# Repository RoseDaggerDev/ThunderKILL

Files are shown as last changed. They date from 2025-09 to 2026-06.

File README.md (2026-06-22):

# ThunderKILL

ThunderKILL is based on the [Thundervolt](https://github.com/mackieks/thundervolt/tree/main) by [YveltalGriffin](https://github.com/mackieks) an open source platform for undervolting the Nintendo Wiis.
ThunderKILL takes the original concept and tries to go overkill with more features explicitly not inculded in the Thundervolt.
### New features:
- USB-C Power delivery
- Battery charge controller
- Fan and temperature controller
- RGB LED controller
- Current sensing
- 5V boost regulator
- E-Fuse on the PD power in
- Resettable fuse on the battery connection

### Existing features from Thundervolt:
- 1V buck regulator
- 1.15V buck regulator
- 1.8V buck regulator
- 3.3V buck boost regulator

All regulators are I2C controlled and high efficiency (η > 90%) and can be(/will be) controllable from a homebrew app. Along with the data from the I2C current/voltage/power sensing and temperature sensing of the board and the Wii.
The ThunderKILL has significantly more output pads than the original Thundervolt, as it is designed to integrate with other boards beyond the Wii itself, supplying easily available power, along with all the new features like PD negotiation, fan and LED outputs.

### ToDo:
- Final pass on board
- Send to printing
- Solder components
- Develop firmware
- Test in isolation
- Test on Wii
- Develop homebrew app

### NOTE: ThunderKILL is still in the prototype phase, and is untested, and the firmware for it has yet to be developed. I don’t recommend manufacturing ThunderKILL PCBs until development and testing are complete. This project is currently only for reference.

(This github page is still WIP, and will change as the project continues)

## Screenshots

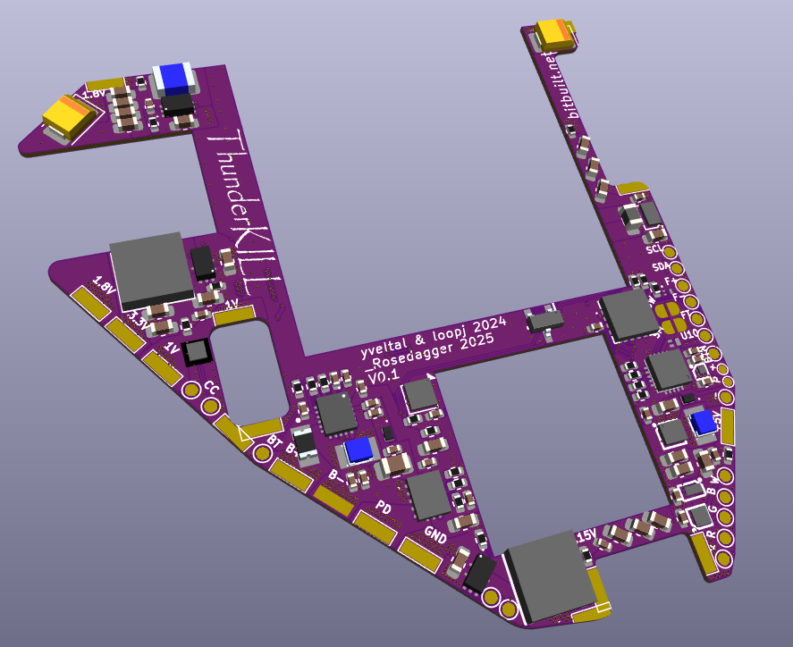
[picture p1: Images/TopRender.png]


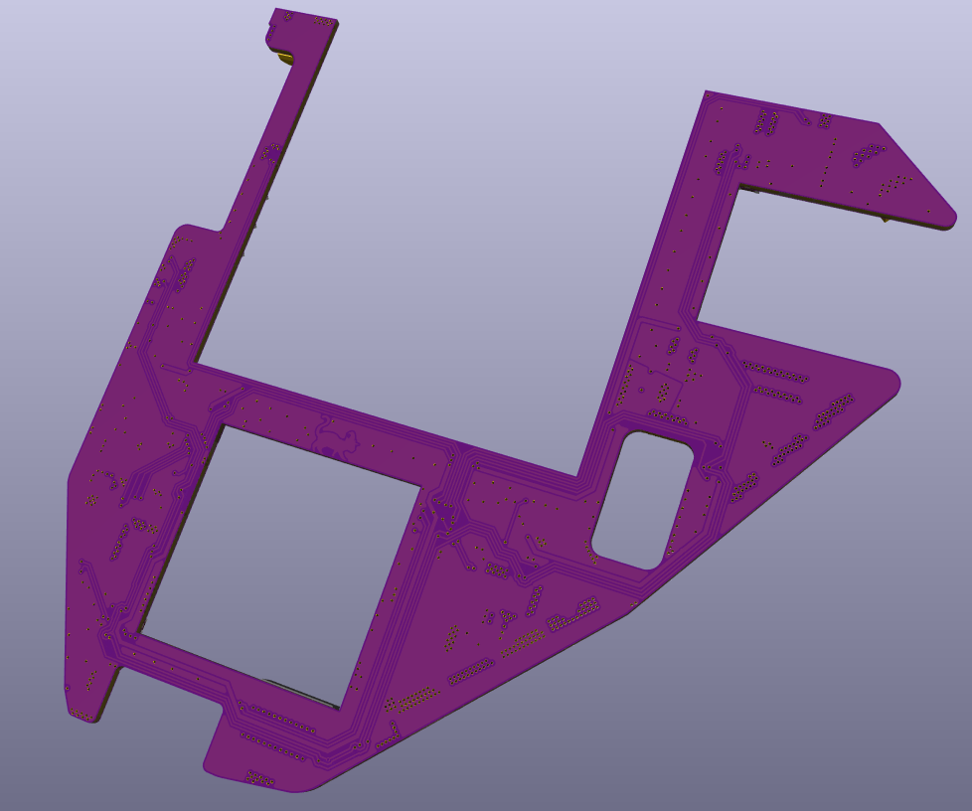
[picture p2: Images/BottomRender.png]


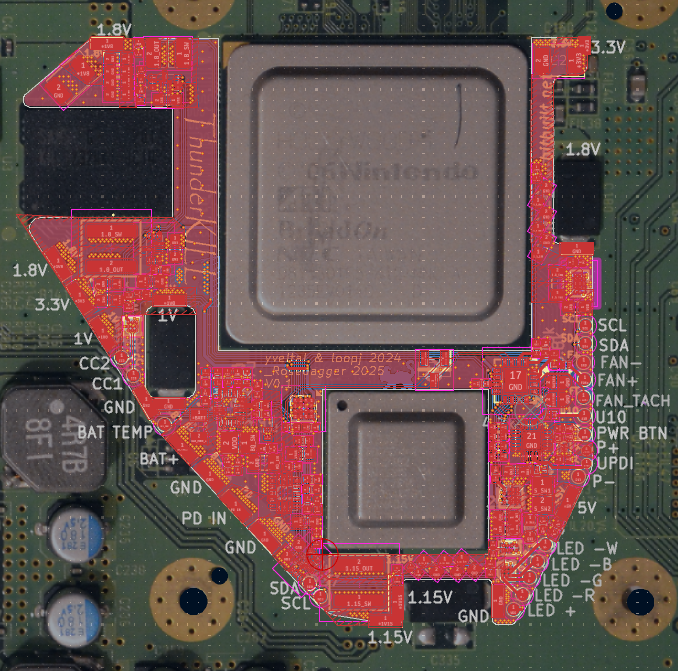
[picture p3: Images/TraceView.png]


## Credits

ThunderKILL hardware designed by [RoseDaggerDev](https://github.com/RoseDaggerDev)

Original Thundervolt credits:

Thundervolt hardware designed by [YveltalGriffin](https://github.com/mackieks)

Thundervolt firmware by [loopj ](https://github.com/loopj)

Thundervolt homebrew by:
- [YveltalGriffin](https://github.com/mackieks) (UI, app)
-  [loopj ](https://github.com/loopj) (I2C, app)
-  [Alex/supertazon](https://github.com/supertazon) (graphics)
-  [ShockSlayer ](https://github.com/ShockSlayer) (music)

## License

ThunderKILL hardware is licensed under Solderpad Hardware License v2.1.

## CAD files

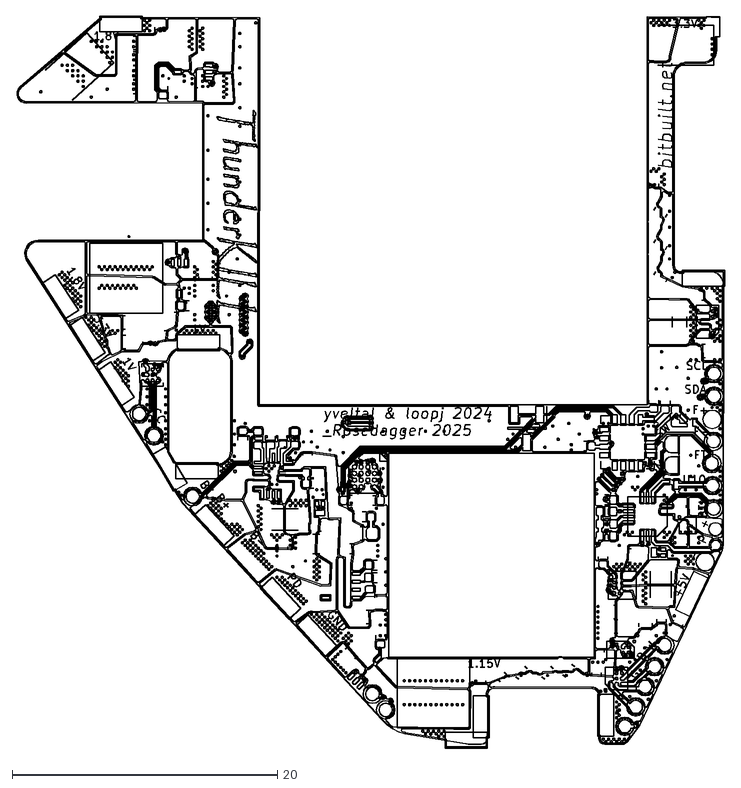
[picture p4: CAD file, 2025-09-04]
Hardware/KiCad/ThunderKillV2/Export/ThunderKillV2-Edge_Cuts.dxf
53.4 x 55.2

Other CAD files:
Hardware/KiCad/ThunderKillV2/Export/thundervolt.stl
Hardware/KiCad/ThunderKillV1/thundervolt.step
Hardware/KiCad/ThunderKillV1/thundervolt.stl

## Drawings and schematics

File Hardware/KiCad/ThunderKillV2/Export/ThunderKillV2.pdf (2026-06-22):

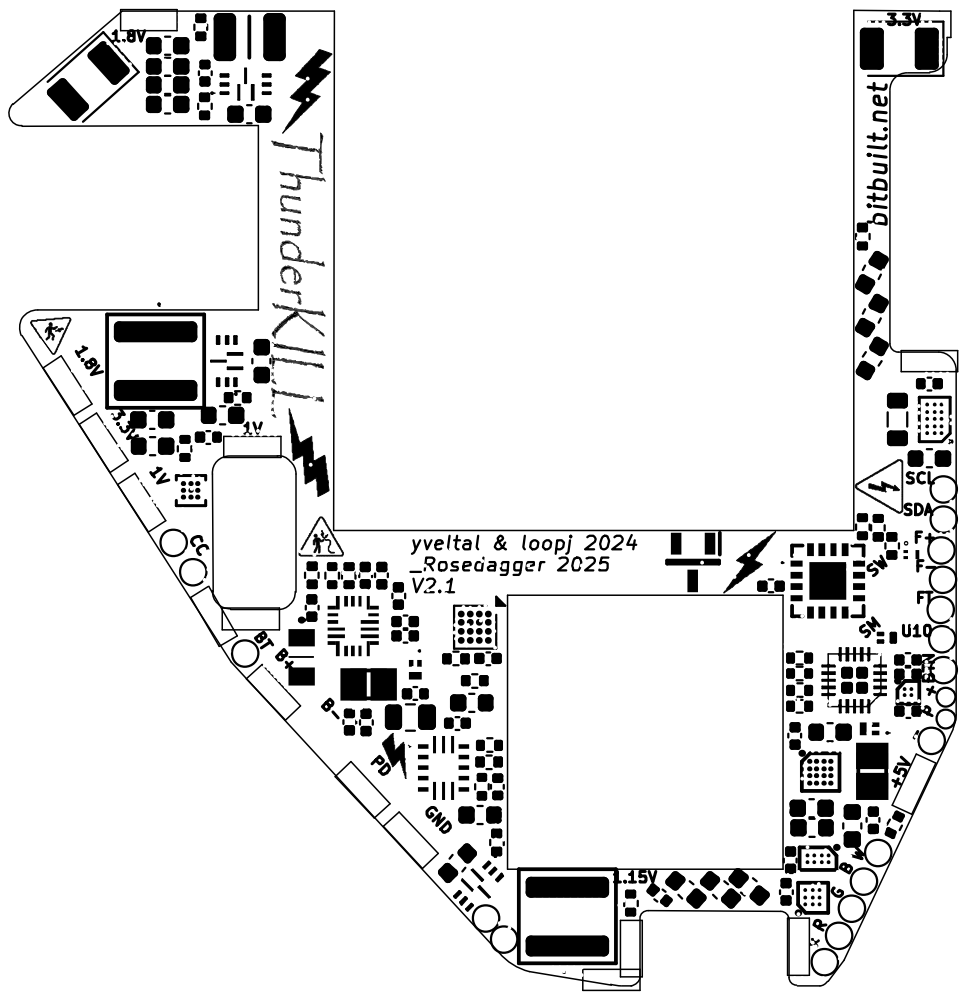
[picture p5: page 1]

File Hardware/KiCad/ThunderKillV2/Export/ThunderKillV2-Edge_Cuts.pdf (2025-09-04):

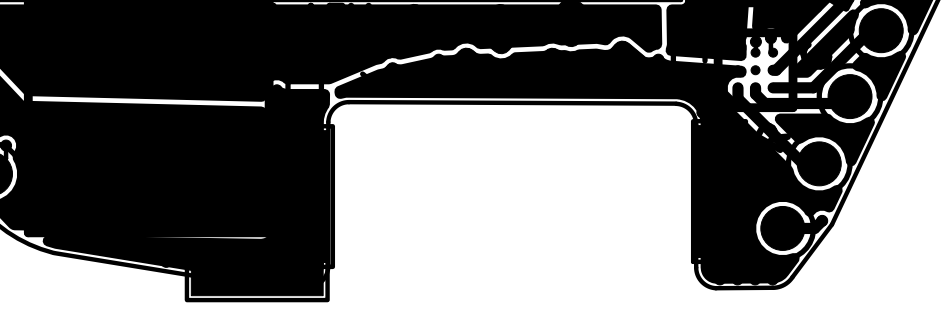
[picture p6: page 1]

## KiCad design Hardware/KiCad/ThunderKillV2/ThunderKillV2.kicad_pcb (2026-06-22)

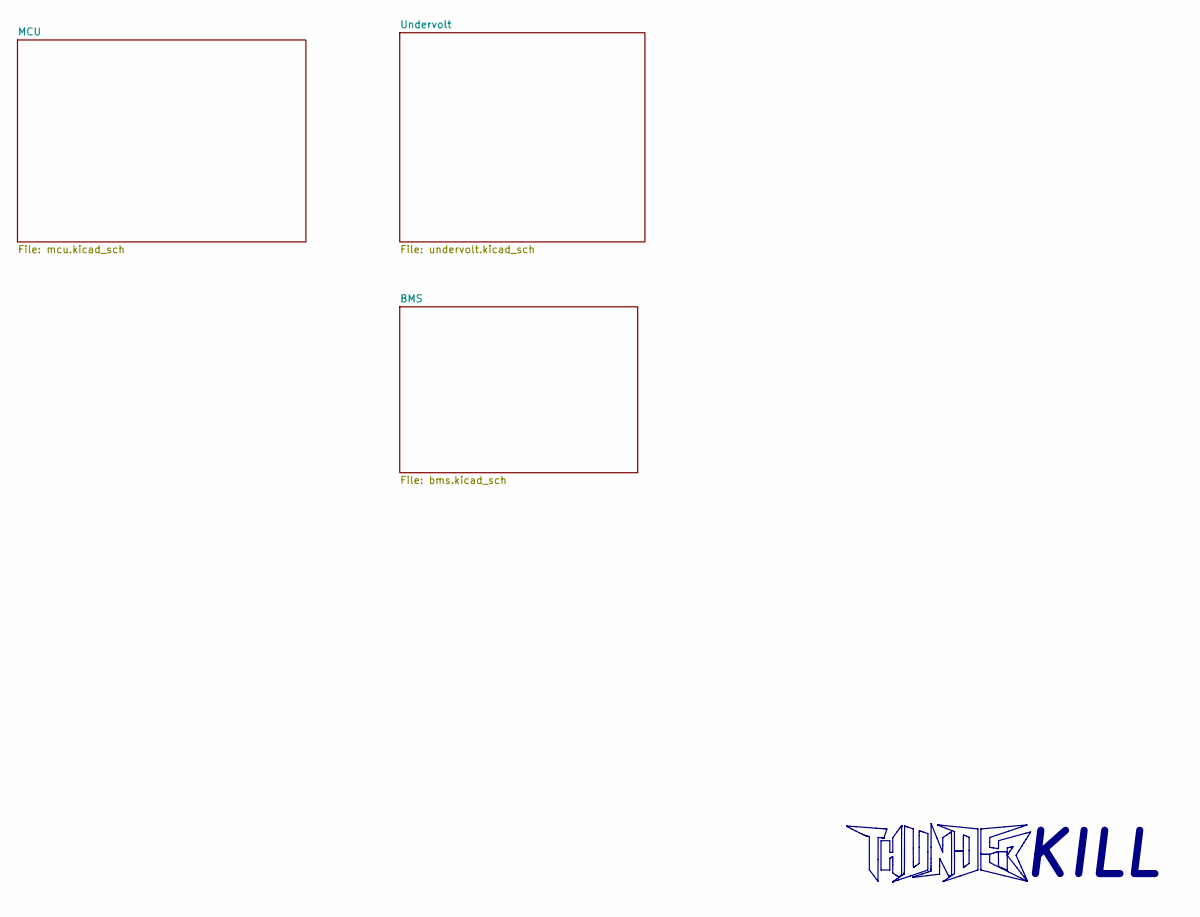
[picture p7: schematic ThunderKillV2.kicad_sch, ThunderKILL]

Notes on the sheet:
KILL

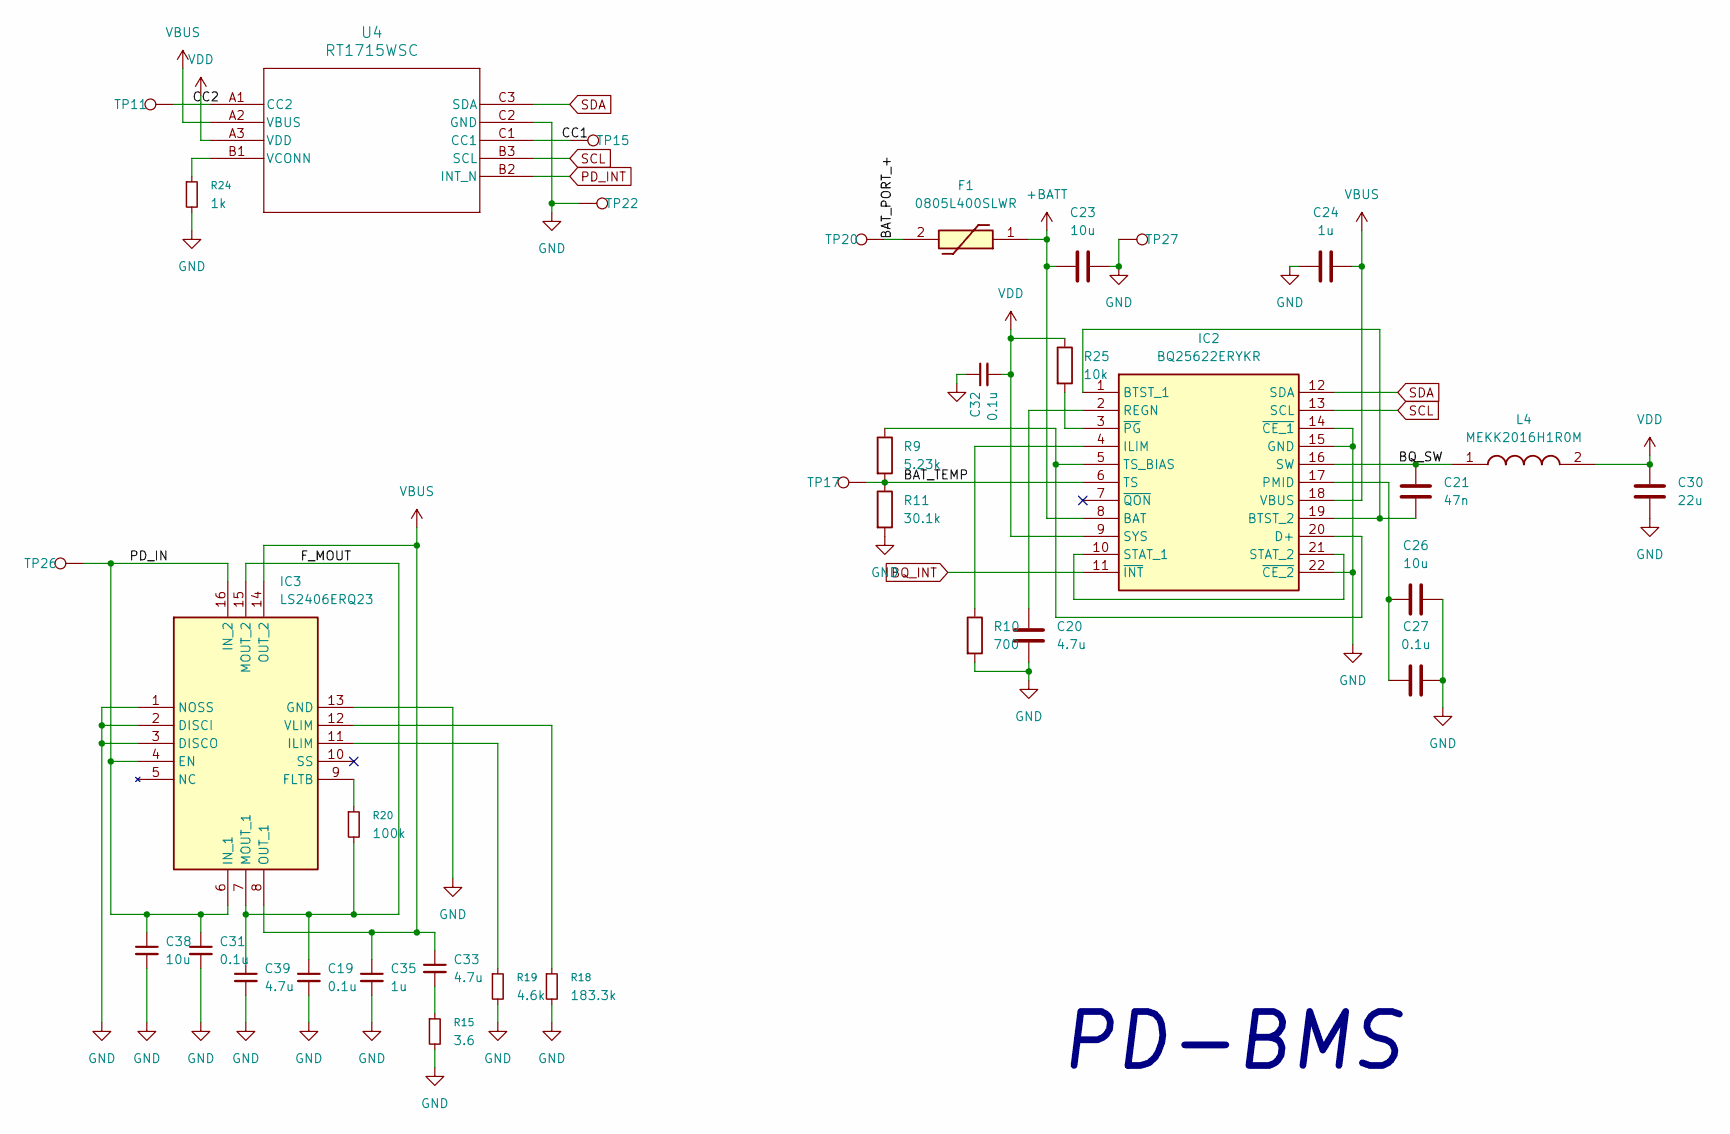
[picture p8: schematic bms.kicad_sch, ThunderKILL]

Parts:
C19, C27, C31, C32: 0.1u; C_0402_1005Metric; Manufacturer_Part_Number GCM155R71H104KE02J; Digi-Key Part # 490-14514-1-ND
C20, C33, C39: 4.7u; C_0402_1005Metric; Manufacturer_Part_Number GRM155C61E475ME15J; Digi-Key Part # 490-GRM155C61E475ME15JCT-ND
C21: 47n; C_0402_1005Metric; Manufacturer_Part_Number GRM155R71H473KE14D; Digi-Key Part # 490-10702-1-ND
C23, C26, C38: 10u; C_0603_1608Metric; Manufacturer_Part_Number GRM188R61E106KA73D; Digi-Key Part # 490-18214-1-ND
C24, C35: 1u; C_0402_1005Metric; Manufacturer_Part_Number GRM155R61E105KA12D; Digi-Key Part # 490-10017-1-ND
C30: 22u; C_0603_1608Metric; Manufacturer_Part_Number GRM188C61E226ME01W; Digi-Key Part # 490-GRM188C61E226ME01WCT-ND
F1: 0805L400SLWR; 0805L075SLYR; Mouser Part Number 576-0805L400SLWR
IC2: BQ25622ERYKR; Mouser Part Number 595-BQ25622ERYKR
IC3: LS2406ERQ23; Mouser Part Number 576-LS2406ERQ23
L4: MEKK2016H1R0M; INDPM2016X100N; Mouser Part Number 963-MEKK2016H1R0M
R9: 5.23k; R_0402_1005Metric; Manufacturer_Part_Number RMCF0402FT5K23; Digi-Key Part # RMCF0402FT5K23CT-ND
R10: 700; R_0402_1005Metric; Manufacturer_Part_Number RMCF0402FT698R; Digi-Key Part # RMCF0402FT698RCT-ND
R11: 30.1k; R_0402_1005Metric; Manufacturer_Part_Number RMCF0402FT30K1; Digi-Key Part # RMCF0402FT30K1CT-ND
R15: 3.6; R_0402_1005Metric; Manufacturer_Part_Number RMCF0402FT3R60; Digi-Key Part # RMCF0402FT3R60CT-ND
R18: 183.3k; R_0402_1005Metric; Manufacturer_Part_Number RMCF0402FT182K; Digi-Key Part # RMCF0402FT182KCT-ND
R19: 4.6k; R_0402_1005Metric; Manufacturer_Part_Number RMCF0402FT4K64; Digi-Key Part # RMCF0402FT4K64CT-ND
R20: 100k; R_0402_1005Metric; Manufacturer_Part_Number CRCW0402100KFKED; Digi-Key Part # 541-100KLCT-ND
R24: 1k; R_0402_1005Metric; Manufacturer_Part_Number CRCW04021K00FKED; Digi-Key Part # 541-1.00KLCT-ND
R25: 10k; R_0402_1005Metric; Manufacturer_Part_Number CRCW040210K0FKED; Digi-Key Part # 541-10.0KLCT-ND
TP11: CC2; TestPoint_Pad_D1.0mm
TP15: CC1; TestPoint_Pad_D1.0mm
TP17: BAT_TMP; TestPoint_Pad_D1.0mm
TP20: BAT+; TestPoint_Pad_3x1.0mm
TP22: GND; TestPoint_Pad_3x1.0mm
TP26: VBUS; TestPoint_Pad_3x1.0mm
TP27: BAT-; TestPoint_Pad_3x1.0mm
U4: RT1715WSC; BGA3X3_RT1715WSC_RIT; Manufacturer_Part_Number RT1715WSC; Digi-Key Part # RT1715WSCCT-ND

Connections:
+BATT: C23.1, F1.1, IC2.8 (BAT)
/BMS/BAT_PORT_+: F1.2, TP20.1
/BMS/BAT_TEMP: IC2.6 (TS), R9.2, R11.1, TP17.1
/BMS/BQ_SW: C21.1, IC2.16 (SW), L4.1
/BMS/CC1: TP15.1, U4.C1 (CC1)
/BMS/CC2: TP11.1, U4.A1 (CC2)
/BMS/F_MOUT: C19.1, C39.1, IC3.7 (MOUT_1), IC3.15 (MOUT_2), R20.2
/BMS/PD_IN: C31.1, C38.1, IC3.4 (EN), IC3.6 (IN_1), IC3.16 (IN_2), TP26.1
BQ_INT: IC2.11 (~INT); also elsewhere on the board
GND: C19.2, C20.2, C23.2, C24.1, C26.2, C27.2, C30.2, C31.2, C32.1, C35.2, C38.2, C39.2, IC2.14 (~CE_1), IC2.15 (GND), IC2.22 (~CE_2), IC3.1 (NOSS), IC3.2 (DISCI), IC3.3 (DISCO), IC3.13 (GND), R10.2, R11.2, R15.2, R18.2, R19.2, R24.2, TP22.1, TP27.1, U4.C2 (GND); also elsewhere on the board
unnamed: C33.2, R15.1
unnamed: C21.2, IC2.1 (BTST_1), IC2.19 (BTST_2)
unnamed: IC2.5 (TS_BIAS), IC2.20 (D+), R9.1
unnamed: IC2.4 (ILIM), R10.1
unnamed: C26.1, C27.1, IC2.17 (PMID)
unnamed: C20.1, IC2.2 (REGN)
unnamed: IC2.10 (STAT_1), IC2.21 (STAT_2)
unnamed: IC2.3 (~PG), R25.2
unnamed: IC3.9 (FLTB), R20.1
unnamed: IC3.11 (ILIM), R19.1
unnamed: IC3.12 (VLIM), R18.1
unnamed: R24.1, U4.B1 (VCONN)
PD_INT: U4.B2 (INT_N); also elsewhere on the board
SCL: IC2.13 (SCL), U4.B3 (SCL); also elsewhere on the board
SDA: IC2.12 (SDA), U4.C3 (SDA); also elsewhere on the board
VBUS: C24.2, C33.1, C35.1, IC2.18 (VBUS), IC3.8 (OUT_1), IC3.14 (OUT_2), U4.A2 (VBUS)
VDD: C30.1, C32.2, IC2.9 (SYS), L4.2, R25.1, U4.A3 (VDD); also elsewhere on the board

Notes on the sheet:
PD-BMS

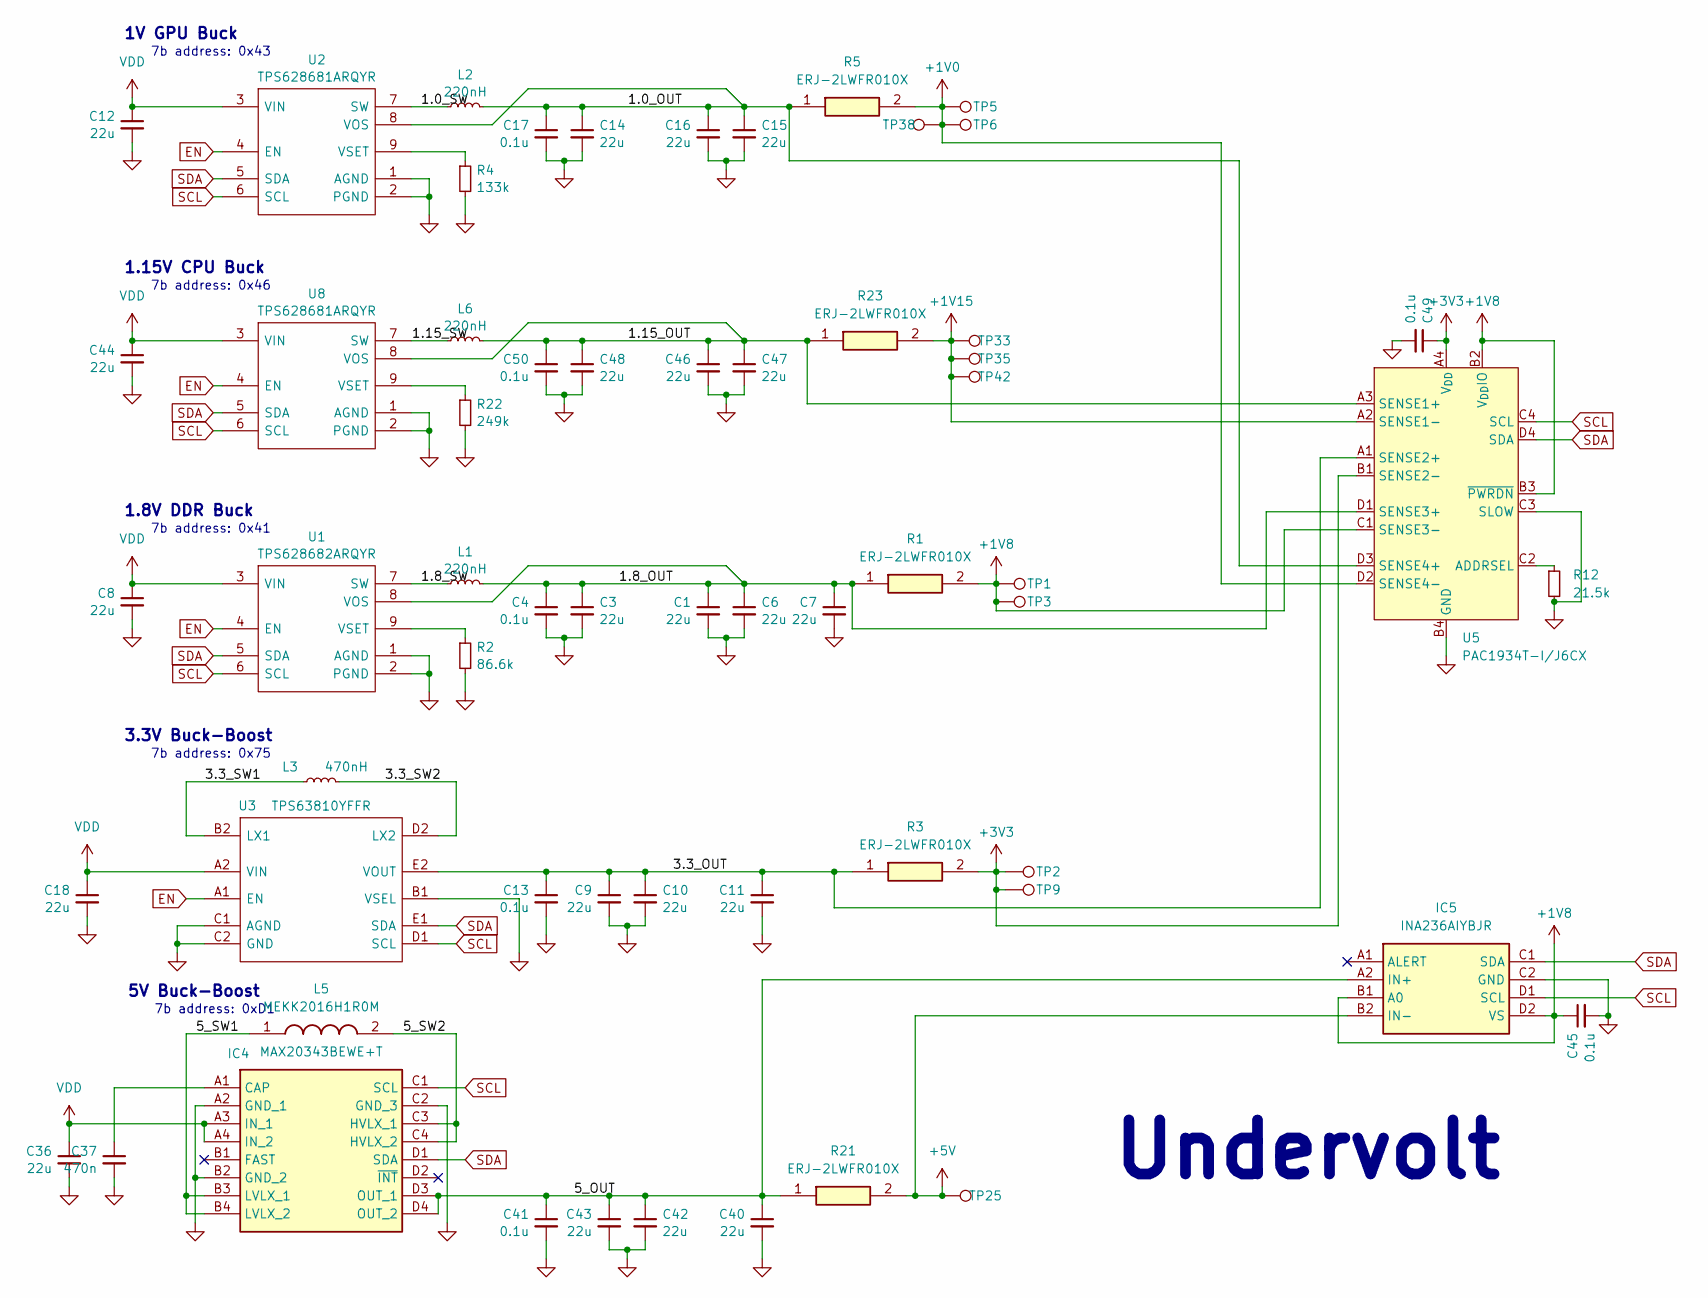
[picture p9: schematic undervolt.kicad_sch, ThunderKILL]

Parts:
C1, C3, C6, C7, C8, C9, C10, C11, C12, C14, C15, C16, C18, C36, C40, C42, C43, C44, C46, C47, C48: 22u; C_0603_1608Metric; Manufacturer_Part_Number GRM188C61E226ME01W; Digi-Key Part # 490-GRM188C61E226ME01WCT-ND
C4, C13, C17, C41, C45, C49, C50: 0.1u; C_0402_1005Metric; Manufacturer_Part_Number GCM155R71H104KE02J; Digi-Key Part # 490-14514-1-ND
C37: 470n; C_0402_1005Metric; Manufacturer_Part_Number GRM155R61E105KA12D; Digi-Key Part # 490-10017-1-ND
IC4: MAX20343BEWE+T; BGA16C40P4X4_201X177X69; Mouser Part Number 700-MAX20343BEWE+T
IC5: INA236AIYBJR; BGA8C40P2X4_70X147X35; Mouser Part Number 595-INA236AIYBJR
L1, L2, L6: 220nH; INDPM4442X150N; Manufacturer_Part_Number MPI4015V2-R22-R; Digi-Key Part # 283-MPI4015V2-R22-RCT-ND
L3: 470nH; L_0805_2012Metric; Manufacturer_Part_Number TFM201208BLE-R47MTCF; Digi-Key Part # 445-TFM201208BLE-R47MTCFCT-ND
L5: MEKK2016H1R0M; INDPM2016X100N; Mouser Part Number 963-MEKK2016H1R0M
R1, R3, R5, R21, R23: ERJ-2LWFR010X; R_0402_1005Metric; Mouser Part Number 667-ERJ-2LWFR010X
R2: 86.6k; R_0402_1005Metric; Manufacturer_Part_Number RMCF0402FT86K6; Digi-Key Part # RMCF0402FT86K6CT-ND
R4: 133k; R_0402_1005Metric; Manufacturer_Part_Number RMCF0402FT133K; Digi-Key Part # RMCF0402FT133KCT-ND
R12: 21.5k; R_0402_1005Metric; Manufacturer_Part_Number RMCF0402FT3R60; Digi-Key Part # RMCF0402FT3R60CT-ND
R22: 249k; R_0402_1005Metric; Manufacturer_Part_Number CRCW0402249KFKED; Digi-Key Part # 541-249KLCT-ND
TP1, TP3: 1V8; TestPoint_Pad_3x1.0mm
TP2: 3V3; TestPoint_Pad_1.5x1.0mm
TP5, TP6, TP38: 1V0; TestPoint_Pad_3x1.0mm
TP9: 3V3; TestPoint_Pad_3x1.0mm
TP25: 5V; TestPoint_Pad_3x1.0mm
TP33, TP35, TP42: 1V15; TestPoint_Pad_3x1.0mm
U1: TPS628682ARQYR; TPS628680ARQYR; Mouser Part Number 595-TPS628682ARQYR
U2, U8: TPS628681ARQYR; TPS628680ARQYR; Mouser Part Number 595-TPS628681ARQYR
U3: TPS63810YFFR; BGA15C40P3X5_134X226X62; Mouser Part Number 595-TPS63810YFFR
U5: PAC1934T-I/J6CX; WLCSP-16_2.225x2.17mm_Layout4x4_P0.5mm; Manufacturer_Part_Number PAC1934T-I/J6CX; Digi-Key Part # PAC1934T-I/J6CX-CT-ND

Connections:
+1V0: R5.2, TP5.1, TP6.1, TP38.1, U5.D2 (SENSE4-)
+1V8: C45.1, IC5.B1 (A0), IC5.D2 (VS), R1.2, TP1.1, TP3.1, U5.B2 (V_{DD}IO), U5.B3 (~PWRDN), U5.C1 (SENSE3-); also elsewhere on the board
+1V15: R23.2, TP33.1, TP35.1, TP42.1, U5.A2 (SENSE1-)
+3V3: C49.1, R3.2, TP2.1, TP9.1, U5.A4 (V_{DD}), U5.B1 (SENSE2-); also elsewhere on the board
+5V: IC5.B2 (IN-), R21.2, TP25.1
/Undervolt/1.0_OUT: C14.1, C15.1, C16.1, C17.1, L2.2, R5.1, U2.8 (VOS), U5.D3 (SENSE4+)
/Undervolt/1.0_SW: L2.1, U2.7 (SW)
/Undervolt/1.8_OUT: C1.1, C3.1, C4.1, C6.1, C7.1, L1.2, R1.1, U1.8 (VOS), U5.D1 (SENSE3+)
/Undervolt/1.8_SW: L1.1, U1.7 (SW)
/Undervolt/1.15_OUT: C46.1, C47.1, C48.1, C50.1, L6.2, R23.1, U5.A3 (SENSE1+), U8.8 (VOS)
/Undervolt/1.15_SW: L6.1, U8.7 (SW)
/Undervolt/3.3_OUT: C9.1, C10.1, C11.1, C13.1, R3.1, U3.E2 (VOUT), U3.E3 (VOUT_2), U5.A1 (SENSE2+)
/Undervolt/3.3_SW1: L3.1, U3.B2 (LX1), U3.B3 (LX1_2)
/Undervolt/3.3_SW2: L3.2, U3.D2 (LX2), U3.D3 (LX2_2)
/Undervolt/5_OUT: C40.1, C41.1, C42.1, C43.1, IC4.D3 (OUT_1), IC4.D4 (OUT_2), IC5.A2 (IN+), R21.1
/Undervolt/5_SW1: IC4.B3 (LVLX_1), IC4.B4 (LVLX_2), L5.1
/Undervolt/5_SW2: IC4.C3 (HVLX_1), IC4.C4 (HVLX_2), L5.2
EN: U1.4 (EN), U2.4 (EN), U3.A1 (EN), U8.4 (EN); also elsewhere on the board
GND: C1.2, C3.2, C4.2, C6.2, C7.2, C8.2, C9.2, C10.2, C11.2, C12.2, C13.2, C14.2, C15.2, C16.2, C17.2, C18.2, C36.2, C37.2, C40.2, C41.2, C42.2, C43.2, C44.2, C45.2, C46.2, C47.2, C48.2, C49.2, C50.2, IC4.A2 (GND_1), IC4.B2 (GND_2), IC4.C2 (GND_3), IC5.C2 (GND), R2.2, R4.2, R12.2, R22.2, U1.1 (AGND), U1.2 (PGND), U2.1 (AGND), U2.2 (PGND), U3.B1 (VSEL), U3.C1 (AGND), U3.C2 (GND), U3.C3 (GND_2), U5.B4 (GND), U5.C3 (SLOW), U8.1 (AGND), U8.2 (PGND); also elsewhere on the board
unnamed: C37.1, IC4.A1 (CAP)
unnamed: R2.1, U1.9 (VSET)
unnamed: R4.1, U2.9 (VSET)
unnamed: R12.1, U5.C2 (ADDRSEL)
unnamed: R22.1, U8.9 (VSET)
SCL: IC4.C1 (SCL), IC5.D1 (SCL), U1.6 (SCL), U2.6 (SCL), U3.D1 (SCL), U5.C4 (SCL), U8.6 (SCL); also elsewhere on the board
SDA: IC4.D1 (SDA), IC5.C1 (SDA), U1.5 (SDA), U2.5 (SDA), U3.E1 (SDA), U5.D4 (SDA), U8.5 (SDA); also elsewhere on the board
VDD: C8.1, C12.1, C18.1, C36.1, C44.1, IC4.A3 (IN_1), IC4.A4 (IN_2), U1.3 (VIN), U2.3 (VIN), U3.A2 (VIN), U3.A3 (VIN_2), U8.3 (VIN); also elsewhere on the board

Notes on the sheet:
1.8V DDR Buck
7b address: 0x75
3.3V Buck-Boost
1.15V CPU Buck
7b address: 0x43
7b address: 0xD1
7b address: 0x41
1V GPU Buck
Undervolt
5V Buck-Boost
7b address: 0x46

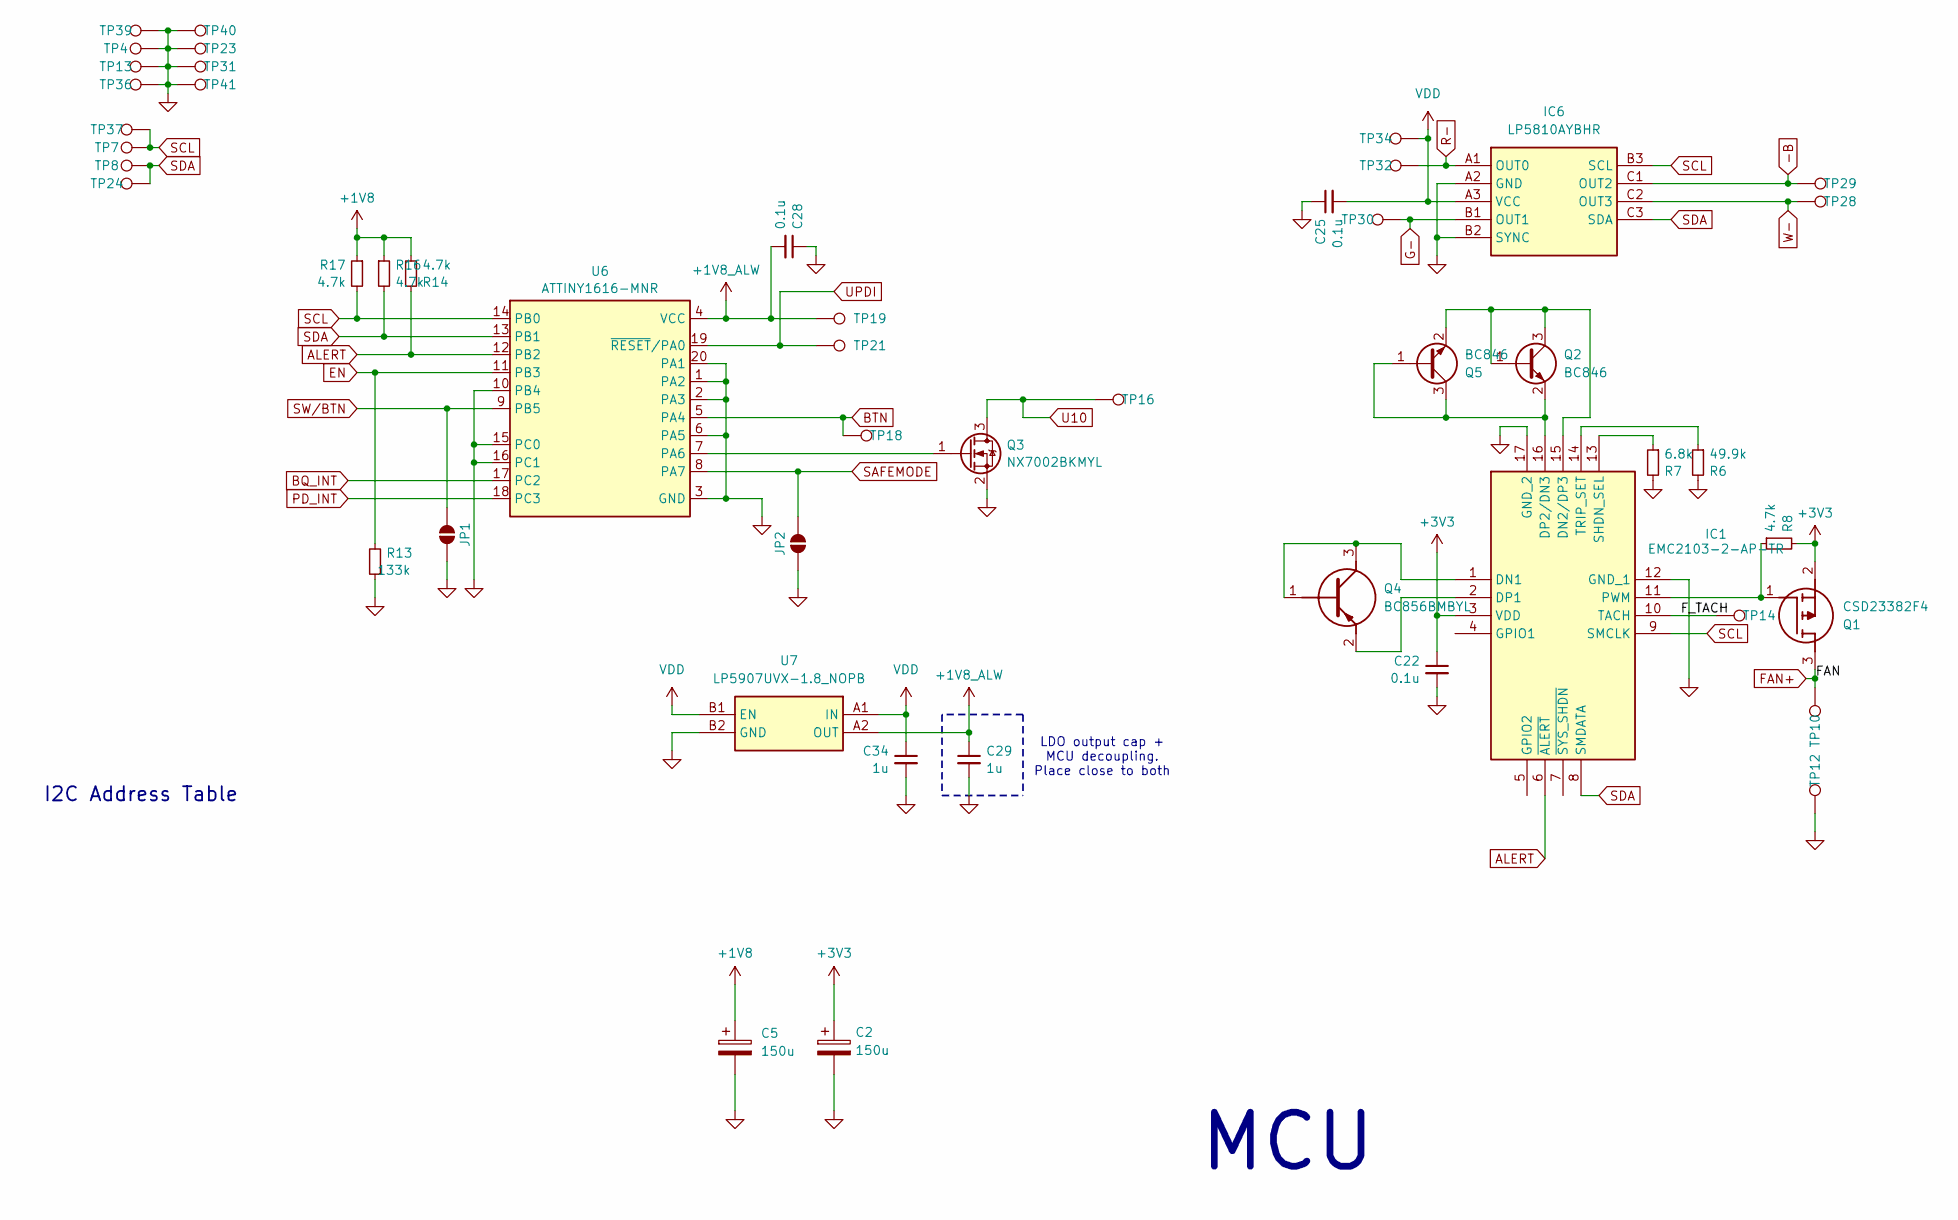
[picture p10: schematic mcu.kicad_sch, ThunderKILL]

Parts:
C2, C5: 150u; CP_EIA-3528-15_AVX-H; Manufacturer_Part_Number 6TPS150MUD; Digi-Key Part # 10-6TPS150MUDCT-ND
C22, C25, C28: 0.1u; C_0402_1005Metric; Manufacturer_Part_Number GCM155R71H104KE02J; Digi-Key Part # 490-14514-1-ND
C29, C34: 1u; C_0402_1005Metric; Manufacturer_Part_Number GRM155R61E105KA12D; Digi-Key Part # 490-10017-1-ND
IC1: EMC2103-2-AP-TR; EMC21032APTR; Mouser Part Number 886-EMC2103-2-AP-TR
IC6: LP5810AYBHR; BGA9C40P3X3_143X134X40; Mouser Part Number 595-LP5810AYBHR
JP1, JP2: SolderJumper_2_Open; SolderJumper-2_P1.3mm_Open_RoundedPad1.0x1.5mm
Q1: CSD23382F4; YJC; Mouser Part Number 595-CSD23382F4
Q2: BC846; SOT-23; Manufacturer_Part_Number BC846B-7-F; Digi-Key Part # BC846B-FDICT-ND
Q3: NX7002BKMYL; Diodes_DFN1006-3; Manufacturer_Part_Number NX7002BKMYL; Digi-Key Part # 1727-2232-1-ND
Q4: BC856BMBYL; Mouser Part Number 771-BC856BMBYL
Q5: BC846; BC856BMBYL; Manufacturer_Part_Number BC846BLP4-7B; Digi-Key Part # BC846BLP4-7BDICT-ND
R6: 49.9k; R_0402_1005Metric; Manufacturer_Part_Number RMCF0402FT49K9; Digi-Key Part # RMCF0402FT49K9CT-ND
R7: 6.8k; R_0402_1005Metric; Manufacturer_Part_Number RMCF0402FT6K80; Digi-Key Part # RMCF0402FT6K80
R8, R14, R16, R17: 4.7k; R_0402_1005Metric; Manufacturer_Part_Number RMCF0402FT4K70; Digi-Key Part # RMCF0402FT4K70CT-ND
R13: 133k; R_0402_1005Metric; Manufacturer_Part_Number RMCF0402FT133K; Digi-Key Part # RMCF0402FT133KCT-ND
TP4, TP13, TP31, TP36, TP39, TP40, TP41: GND; TestPoint_Pad_3x1.0mm
TP7, TP37: SCL; TestPoint_Pad_D1.0mm
TP8, TP24: SDA; TestPoint_Pad_D1.0mm
TP10: FAN+; TestPoint_Pad_D1.0mm
TP12: FAN-; TestPoint_Pad_D1.0mm
TP14: FAN_TACH; TestPoint_Pad_D1.0mm
TP16, TP23: U10; TestPoint_Pad_D1.0mm
TP18: BTN; TestPoint_Pad_D1.0mm
TP19: VBAT; TestPoint_Pad_D1.0mm
TP21: UPDI; TestPoint_Pad_D1.0mm
TP28: LED -W; TestPoint_Pad_D1.0mm
TP29: LED -B; TestPoint_Pad_D1.0mm
TP30: LED -G; TestPoint_Pad_D1.0mm
TP32: LED -R; TestPoint_Pad_D1.0mm
TP34: LED +; TestPoint_Pad_D1.0mm
U6: ATTINY1616-MNR; VQFN-20-1EP_3x3mm_P0.4mm_EP1.7x1.7mm; Manufacturer_Part_Number ATTINY1616-MNR; Digi-Key Part # ATTINY1616-MNRCT-ND
U7: LP5907UVX-1.8_NOPB; BGA4C35P2X2_64X64X44; Mouser Part Number 926-LP5907UVX1.8NOPB

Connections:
+1V8: C5.1, R14.2, R16.1, R17.1; also elsewhere on the board
+1V8_ALW: C28.2, C29.1, TP19.1, U6.4 (VCC), U7.A2 (OUT)
+3V3: C2.1, C22.1, IC1.3 (VDD), Q1.2 (S), R8.2; also elsewhere on the board
-B: IC6.C1 (OUT2), TP29.1
/MCU/F_TACH: IC1.10 (TACH), TP14.1
ALERT: IC1.6 (~ALERT), R14.1, U6.12 (PB2)
BQ_INT: U6.17 (PC2); also elsewhere on the board
BTN: TP18.1, U6.5 (PA4)
EN: R13.2, U6.11 (PB3); also elsewhere on the board
FAN+: Q1.3 (D), TP10.1
G-: IC6.B1 (OUT1), TP30.1
GND: C2.2, C5.2, C22.2, C25.1, C28.1, C29.2, C34.2, IC1.12 (GND_1), IC1.17 (GND_2), IC6.A2 (GND), IC6.B2 (SYNC), JP1.1 (A), JP2.1 (A), Q3.2 (S), R6.2, R7.2, R13.1, TP4.1, TP12.1, TP13.1, TP23.1, TP31.1, TP36.1, TP39.1, TP40.1, TP41.1, U6.1 (PA2), U6.2 (PA3), U6.3 (GND), U6.6 (PA5), U6.10 (PB4), U6.15 (PC0), U6.16 (PC1), U6.20 (PA1), U6.21 (GND), U7.B2 (GND); also elsewhere on the board
unnamed: IC1.1 (DN1), Q4.1 (B), Q4.3 (C)
unnamed: IC1.15 (DN2/DP3), Q2.1 (B), Q2.3 (C), Q5.2 (E)
unnamed: IC1.2 (DP1), Q4.2 (E)
unnamed: IC1.16 (DP2/DN3), Q2.2 (E), Q5.1 (B), Q5.3 (C)
unnamed: IC1.11 (PWM), Q1.1 (G), R8.1
unnamed: IC1.13 (SHDN_SEL), R7.1
unnamed: IC1.14 (TRIP_SET), R6.1
unnamed: Q3.1 (G), U6.7 (PA6)
PD_INT: U6.18 (PC3); also elsewhere on the board
R-: IC6.A1 (OUT0), TP32.1
SAFEMODE: JP2.2 (B), U6.8 (PA7)
SCL: IC1.9 (SMCLK), IC6.B3 (SCL), R17.2, TP7.1, TP37.1, U6.14 (PB0); also elsewhere on the board
SDA: IC1.8 (SMDATA), IC6.C3 (SDA), R16.2, TP8.1, TP24.1, U6.13 (PB1); also elsewhere on the board
SW/BTN: JP1.2 (B), U6.9 (PB5)
U10: Q3.3 (D), TP16.1
UPDI: TP21.1, U6.19 (~RESET/PA0)
VDD: C25.2, C34.1, IC6.A3 (VCC), TP34.1, U7.A1 (IN), U7.B1 (EN); also elsewhere on the board
W-: IC6.C2 (OUT3), TP28.1

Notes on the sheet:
I2C Address Table
MCU
LDO output cap + MCU decoupling. Place close to both

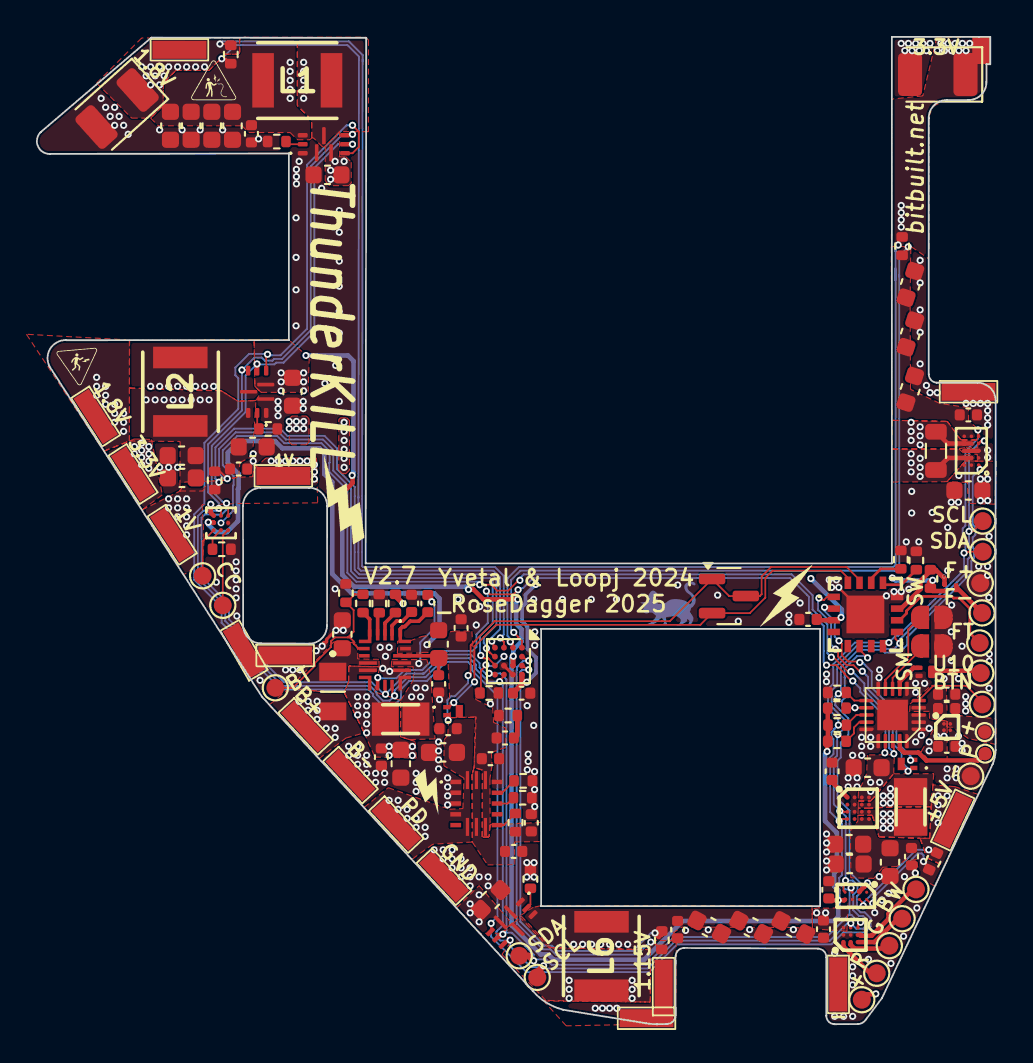
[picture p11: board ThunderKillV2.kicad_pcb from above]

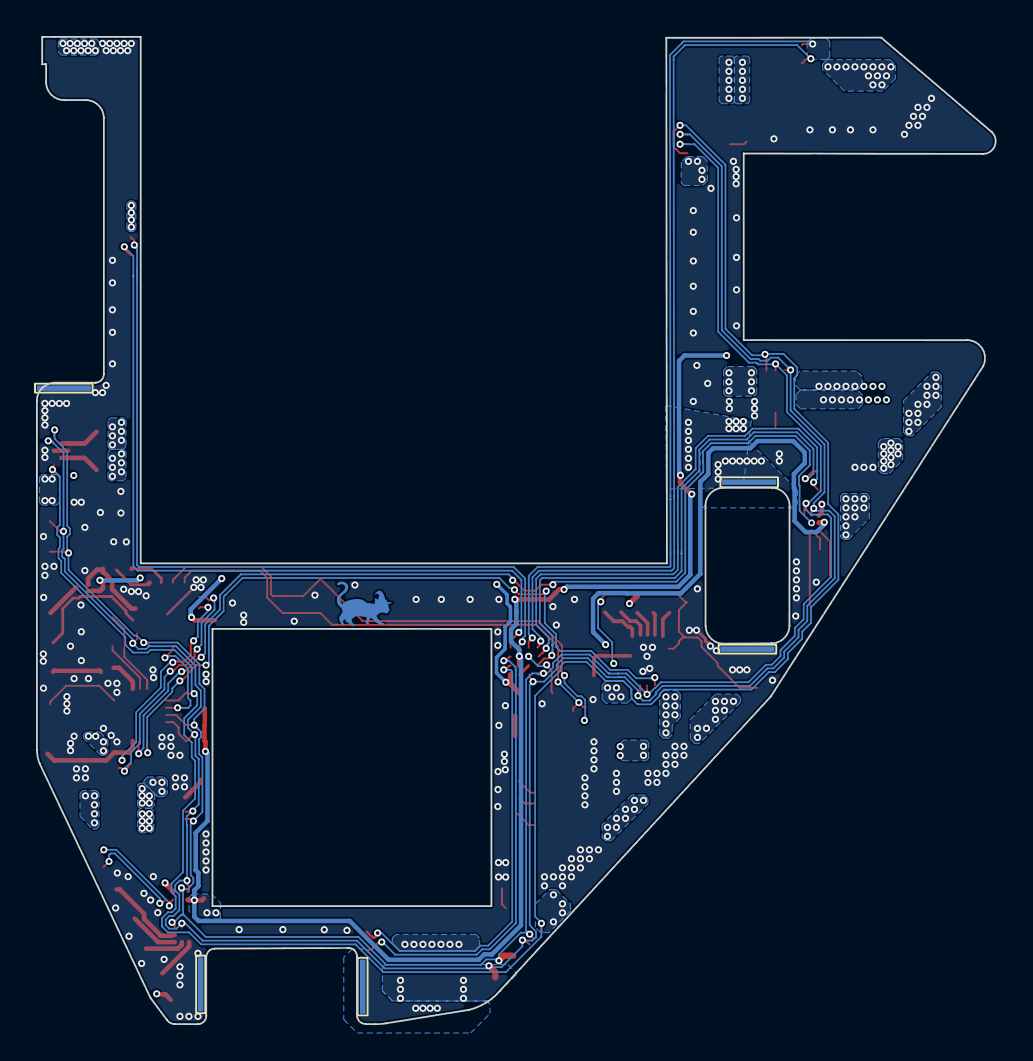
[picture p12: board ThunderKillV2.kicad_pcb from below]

Board: 4 copper layers, 53.3 x 54.8 mm, 145 parts (5 on the bottom side), 71 nets.

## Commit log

2025-09-04 Updated thunderkill to V2 near production ready
    [PD.kicad_sch, ThunderKill.kicad_sch, ThunderKillV2-Edge_Cuts.dxf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]
2025-09-05 Updated to fix 3d file paths, and updated page settings with version number and author.
    Also updated the name for ThunderKILL V1
    [PD.kicad_sch, ThunderKillV1.kicad_sch, ThunderKillV2-Edge_Cuts.dxf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]
2026-06-22 Updating to newest local version
    [ThunderKillV2.kicad_pcb, bms.kicad_sch, mcu.kicad_sch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]
